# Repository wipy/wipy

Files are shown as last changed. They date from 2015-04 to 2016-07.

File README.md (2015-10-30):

The WiPy project
========================
<p align="center">
  The WiPy Logo
</p>

This is the WiPy project which aims to offer a powerful, simple,
yet flexible IoT hardware and software solution. This is achieved by
combining MicroPython (https://github.com/micropython/micropython),
a lean and mean implementation of Python 3 targeted to microcontrollers,
with the CC3200 from Texas Instruments, a state of the art SoC that
combines a Cortex-M4 MCU with an ultra low power WiFi network processor.

Components in this repository:
- docs/ -- API documentation.
- hardware/ -- Schematics, and PCB files of the WiPy.
- micropython/ -- Contains the MicroPython sources (as a git submodul) used to built the latest WiPy SW release.
- misc/ -- Miscellaneous stuff like the WiPy logo.

The micropython folder is a git submodule pointing to the micropython repository, check it out with:

    $ git submodule update --init

"make" is used to build the software, or "gmake" on BSD-based systems.
You will also need bash and Python (at least 2.7 or 3.3).

To build:

    $ cd cc3200
    $ make BTARGET=application BTYPE=release BOARD=WIPY

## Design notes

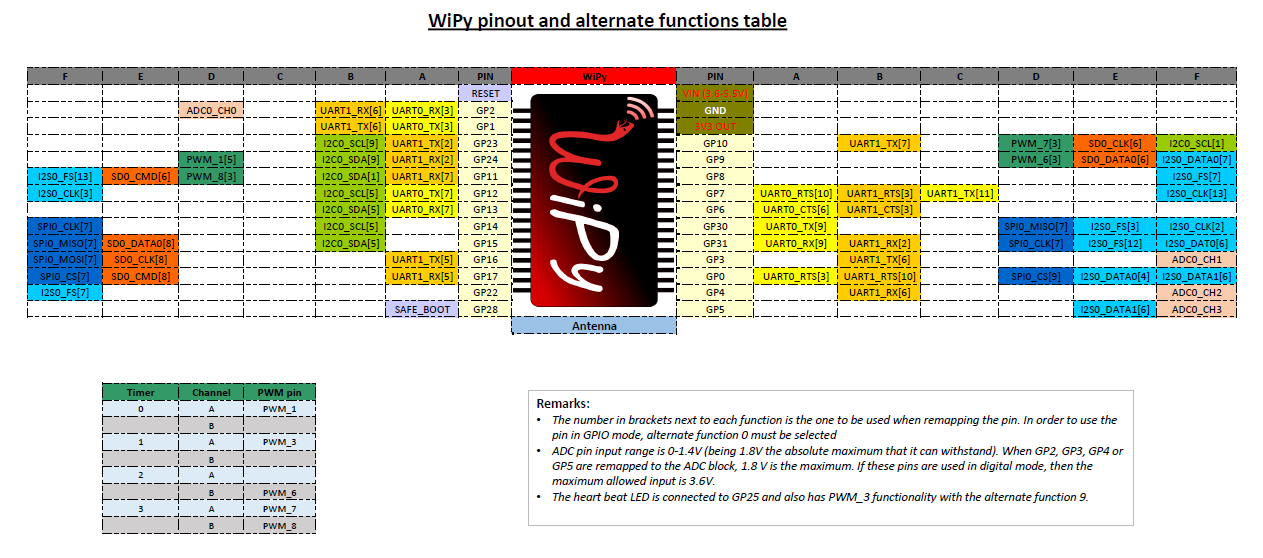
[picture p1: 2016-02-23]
docs/PinOUT.png

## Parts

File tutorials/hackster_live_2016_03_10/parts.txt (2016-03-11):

What we need:

- 1x WiPy
- 1x Expanion board
- 1x DS18B20 temperature sensor
- 1x 4k7 ohm resistor
- 1x BH1750FVI ambient light sensor
- 1x Small breadboard
- Bread board compatible cables.
- A tablet or smartphone with the Blynk App installed.
- Internet acces via WiFi for the WiPy.

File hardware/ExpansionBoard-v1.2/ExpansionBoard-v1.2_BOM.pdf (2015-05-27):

Description | RefDes | Manufacturer | Manufacturer Part No. | Quantity
Resistor_0402_63mW_5%, 27R | R5, R6 | | | 2
Resistor_0402_63mW_1%, 392R | R15 | | | 1
Resistor_0402_63mW_1%, 1K2 | R1, R3, R4, R8, R10, R13 | | | 6
Resistor_0402_63mW_1%, 2k | R11 | | | 1
Resistor_0402_63mW_5%, 10k | R12 | | | 1
Resistor_0402_63mW_1%, 56k | R16 | | | 1
Resistor_0402_63mW_5%, 100k | R2, R7, R9 | | | 3
Resistor_0402_63mW, 115k | R14 | | | 1
Ceramic_0402_NP0, 47pF/50V | C7, C8 | | | 2
Ceramic_0402_X5R, 0.1µF/10V | C2, C4, C5, C6, C9, C12, C13, 14 | | | 8
Ceramic_0603_X5R, 1µF/10V | C11 | | | 1
Ceramic_0805_X5R, 10µF/10V | C3, C10 | | | 2
FerriteBead_0805, BLM21PG600SN1D | L1 | MURATA | BLM21PG600SN1D | 1
LED_0603, LED_GREEN | D1, D2 | KINGBRIGHT | KPT-1608SGC | 2
LED_0603, LED_RED | D3 | KINGBRIGHT | KPT-1608EC | 1
P_Channel, FDC6333C | T2 | FAIRCHILD SEMICONDUCTOR | FDC6333C | 1
P_Channel, FDMA291P | T1 | FAIRCHILD SEMICONDUCTOR | FDMA291P | 1
USB_BRIDGE, FT234XD | U1 | FTDI | FT234XD-R | 1
CHARGERS, bq24040 | U2 | TEXAS INSTRUMENTS | BQ24040DSQR | 1
MUX, TPS2115A | U3 | TEXAS INSTRUMENTS | TPS2115ADRBR | 1
Connector_JST, JST | J16 | JST | S2B-XH-A (LF)(SN) | 1
Connector_SD, SD-105027-001 | J3 | MOLEX | 105027-0001 | 1
Connector_SSQ, SSQ-114-03-G-S | J1, J2, J4, J5 | SAMTEC | SSQ-114-02-G-S-RA | 4
Connector_USB, MICROUSB | J15 | FCI | 10118192-0001LF | 1
Jumpers, JUMPER 2 2.54mm | JP3 | | | 7
SWITCHES, TS-1185 | S1 | Hooya | TS-1185 | 1
Total | 53

Bill of materials - WiPy Expansion board v1.2

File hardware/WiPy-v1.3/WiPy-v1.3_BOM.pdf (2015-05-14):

Description | RefDes | Manufacturer | Manufacturer Part No. | Quantity
Resistor_0402_100mW_5%, 270R | R1 | | | 1
Resistor_0402_63mW_5%, 2K7 | R11 | | | 1
Resistor_0402_63mW_5%, 10k | R3 | | | 1
Resistor_0402_63mW_1%, 30K1 | R16 | | | 1
Resistor_0402_63mW_1%, 51K | R15 | | | 1
Resistor_0402_63mW_5%, 100k | R2, R4, R6, R9, R10, R12, R13, R14 | | | 8
Ceramic_0402_NP0, 6.2pF/50V | C10, C11 | | | 2
Ceramic_0402_NP0, 10pF/50V | C2, C3, C4, C5, C6 | | | 5
Ceramic_0402_NP0, 18pF/50V | C31 | | | 1
Ceramic_0402_NP0, 33pF/50V | C1, C7 | | | 2
Ceramic_0402_X5R, 0.1µF/10V | C8, C9, C15, C16, C17, C21, C22, C23, C25, C26, C27, C28, C29 | | | 13
Ceramic_0402_X5R, 4.7µF/6V3 | C12, C13, C14 | | | 3
Ceramic_0603_X5R, 10µF/6.3V | C20, C24 | | | 2
Ceramic_0603_X5R, 22µF/6.3V | C18, C19 | | | 2
Ceramic_0805_X5R, 10µF/10V | C30, C32 | | | 2
INDUCTORS, LQM2HPN1R0MJ0L | L2 | Murata | LQM2HPN1R0MJ0L | 1
INDUCTORS, LQM2HPN2R2MG0L | L1, L3 | Murata | LQM2HPN2R2MG0L | 2
Filters, DEA202450BT-1294C1-H | FL1 | TDK-Epcos | DEA202450BT-1294C1-H | 1
LED_0603, LED_BLUE | D1 | EVERLIGHT | 19-217/BHC-ZL1M2RY/3T | 1
N_CHANNEL, BSS138PW | T1 | NXP | BSS138PW | 1
P_Channel, FDMA291P | T2 | FAIRCHILD SEMICONDUCTOR | FDMA291P | 1
Crystals, 32.768kHz, 12.5pF | X1 | ABRACON | ABS07-32.768KHZ-T | 1
CRYSTALS, 40.000MHZ, 8pF | X2 | AVX | CX2520DB40000D0FLJCC | 1
FlashMemory, W25Q16DVZPIG | U3 | Winbond | W25Q16DVZPIG | 1
LowDrop, TPS79601DRB | U4 | TEXAS INSTRUMENTS | TPS79601DRBR | 1
RF_SWITCH, SKY13350-385LF | U2 | Skyworks | SKY13350-385LF | 1
TI, CC3200R1M2 | U1 | Texas Instruments | CC3200R1M2RGC | 1
SWITCHES, TS-1185 | S1 | Hooya | TS-1185 | 1
UFL, HJBRIGHT | ANT2 | HJBRIGHT | P1163-0140R | 1
Antennas, FR05-S1-N-0-001 | ANT1 | Fractus | FR05-S1-N-0-001 | 1
Total | | | | 61

## Bill of materials - WiPy v1.3

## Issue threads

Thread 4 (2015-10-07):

Hidden messages in PinOUT.xlsx

doctorjames, 2015-10-07:
I've just noticed there appears to be some advertising hidden in white text in the background of the pin out diagram. Not speaking Dutch, I'm not entirely sure what it says!

danicampora, 2015-10-07:
Hi @doctorjames can you show me where? (screenshot maybe...) I cannot see it...

doctorjames, 2015-10-07:
Sure, see attached. (Strangely github wouldn't accept a pdf upload despite claiming it did.)

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

dpgeorge, 2015-10-07:
oops!

danicampora, 2015-10-18:
Solved in https://github.com/wipy/wipy/commit/1b79563e3fb67ecc0384bc383f4ec1930fc9d5b2

Closed 2015-10-18.

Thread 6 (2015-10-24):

User manual Super expansion board incomplete

Mast3rChief, 2015-10-24:
The user manual is incomplete.
- For example a list of abbreviation is missing.
- I have trouble finding out how to use the user button or switch.

My suggestion is, could you upload the latex file or the raw file you used to compile the PDF. One could add information to the manual for better understanding.

danicampora, 2015-10-24:
Thanks, we'll look into that.

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

mbevilacqua, 2016-05-06:
What user manual? I didn't get any user manual with the WiPy's not the expansion boards... :-?

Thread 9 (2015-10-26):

Source download of release is missing source

doctorjames, 2015-10-26:
The tar and zip files of the new release do not include the actual source contained in the **micropython** git submodule. The **README.md** states to:

    cd cc3200
    make BTARGET=application BTYPE=release BOARD=WIPY

If the sourcecode was actually there, from the location of **README.md** presumably this should be:

    cd micropython/cc3200

You also need some instructions on setting up cross-compiling. On *debian* this involves:

    sudo apt-get install gcc-arm-none-eabi

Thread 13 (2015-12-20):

Timer class is broken

deshipu, 2015-12-20:
As per http://forum.micropython.org/viewtopic.php?f=11&t=1057&p=7646 the Timer class examples from the documentation don't work and according to @danicampora the whole class needs fixing.

deshipu, 2016-02-23:
I saw the release https://github.com/wipy/wipy/releases/tag/1.2.0 and since it mentions fixing the Timer class, I tried it immediately. Unfortunately, while I didn't get an error with ``freq=50`` this time, I also couldn't get a PWM signal on any pin.

It seems that as soon as I initialize the channel corresponding to a pin into PWM mode, that pin switches to ``Pin.IN`` mode.

danicampora, 2016-02-23:
Hi @deshipu,

Please check the docs again, since the API is has changed a bit. First of all Timer IDs start at 0 now (but you already got that right), also since the PWM dutcy cycle with 1% resolution was very bad, not the resolution has been change to 0.01% using fixed point, so, if you want a duty cycle of 50.15, then you have to pass 5015 as value. Also, since PWM pins are fixed, when creating a PWM channel, the corresponding Pin is automatically configured in PWM mode. Try this:

```python
from machine import Timer

tim = Timer(0, mode=Timer.PWM)
ch = tim.channel(Timer.A, freq=50, duty_cycle=5000)
```
And that will create a 50Hz duty cycle PWM signal on GP24 with a 50% duty cycle.

Docs link: https://micropython.org/resources/docs/en/latest/wipy/library/machine.Timer.html

Cheers,
Daniel

P.S.: Sorry for the super long delay on this fix...

bulislaw, 2016-02-23:
Ha! It works now, thanks :) Just one one day after I got my servo!

danicampora, 2016-02-23:
Haha awesome! Post some videos if you can :-)

Cheers,
Daniel

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

Closed 2016-02-23.

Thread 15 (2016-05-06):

Missing manual for the Expansion Board v2.1 (2016)

mbevilacqua, 2016-05-06:
Expansion board feels nice but a manual would be much better.

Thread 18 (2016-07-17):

Later releases are available directly from micropython.org.

gpshead, 2016-07-17:
Is this repo still useful? The latest releases of MicroPython for the WiPy seem to be available directly from https://micropython.org/download/ rather than the rather "old" 1.6 release currently available here.

niallp, 2017-01-27:
I tried building from the micropython head (v1.8.7) and while I got mcuimg.bin without errors and it nominally runs, the ftp server hangs on login (so updating firmware needs a safeboot etc.)

wipy release numbering seems to have been reset, most recent is 1.3.0, using v1.8.2 of micropython

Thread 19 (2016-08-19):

WiPy is behind MicroPython mainline in updates

pfalcon, 2016-08-19:
From https://github.com/wipy/wipy/releases/tag/v1.3.0:

> Update to release v1.8.2.

Why update to a previous release, if 1.8.3 is out for couple of weeks? There were already reports of people trying some features from micropython-lib (which is in general require the latest release of MicroPython), and having issues.

niallp, 2017-01-27:
the ftp server appears broken in a build of the latest micropython (v1.8.7), it appears the wipy 1.0 is yet another orphan (getting quite the collection ... :-/

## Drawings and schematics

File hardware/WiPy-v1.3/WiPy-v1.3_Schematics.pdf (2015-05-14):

## VCC_3V3

## Vsys

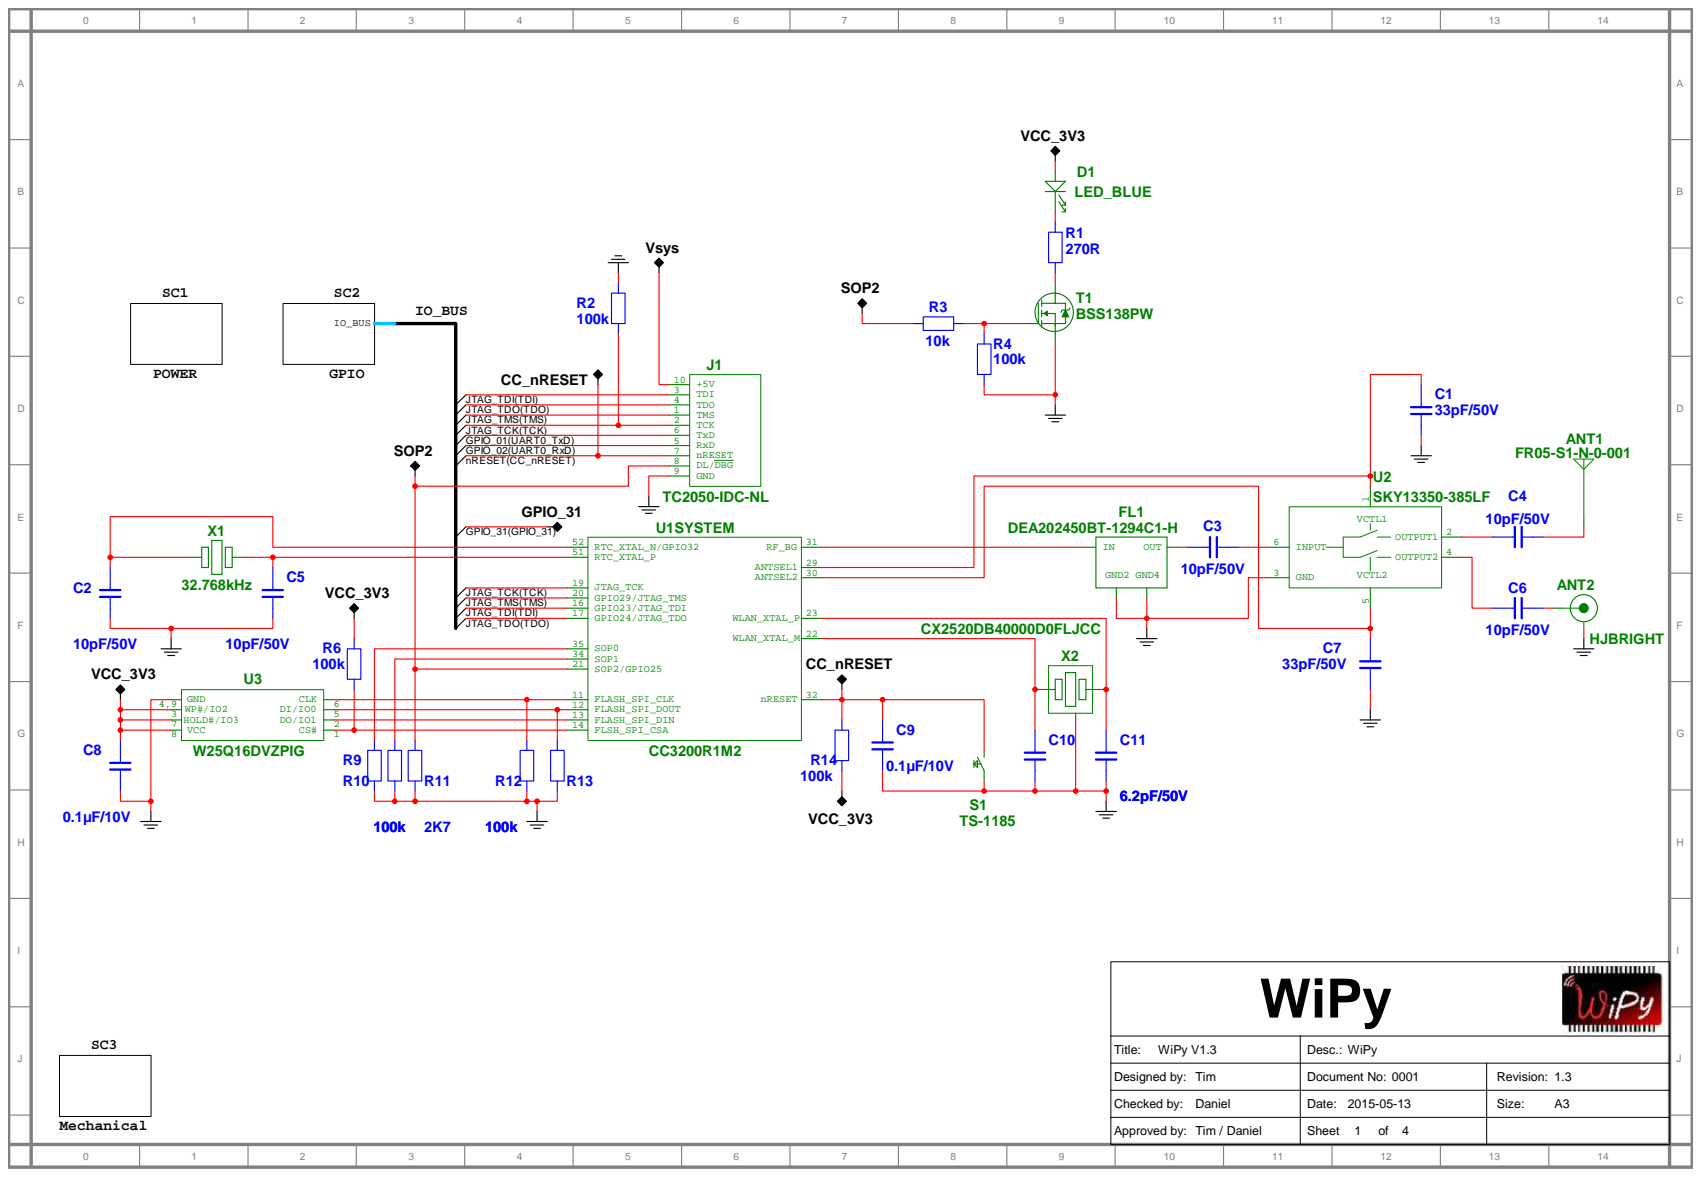
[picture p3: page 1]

## IO_BUS

## U1IO

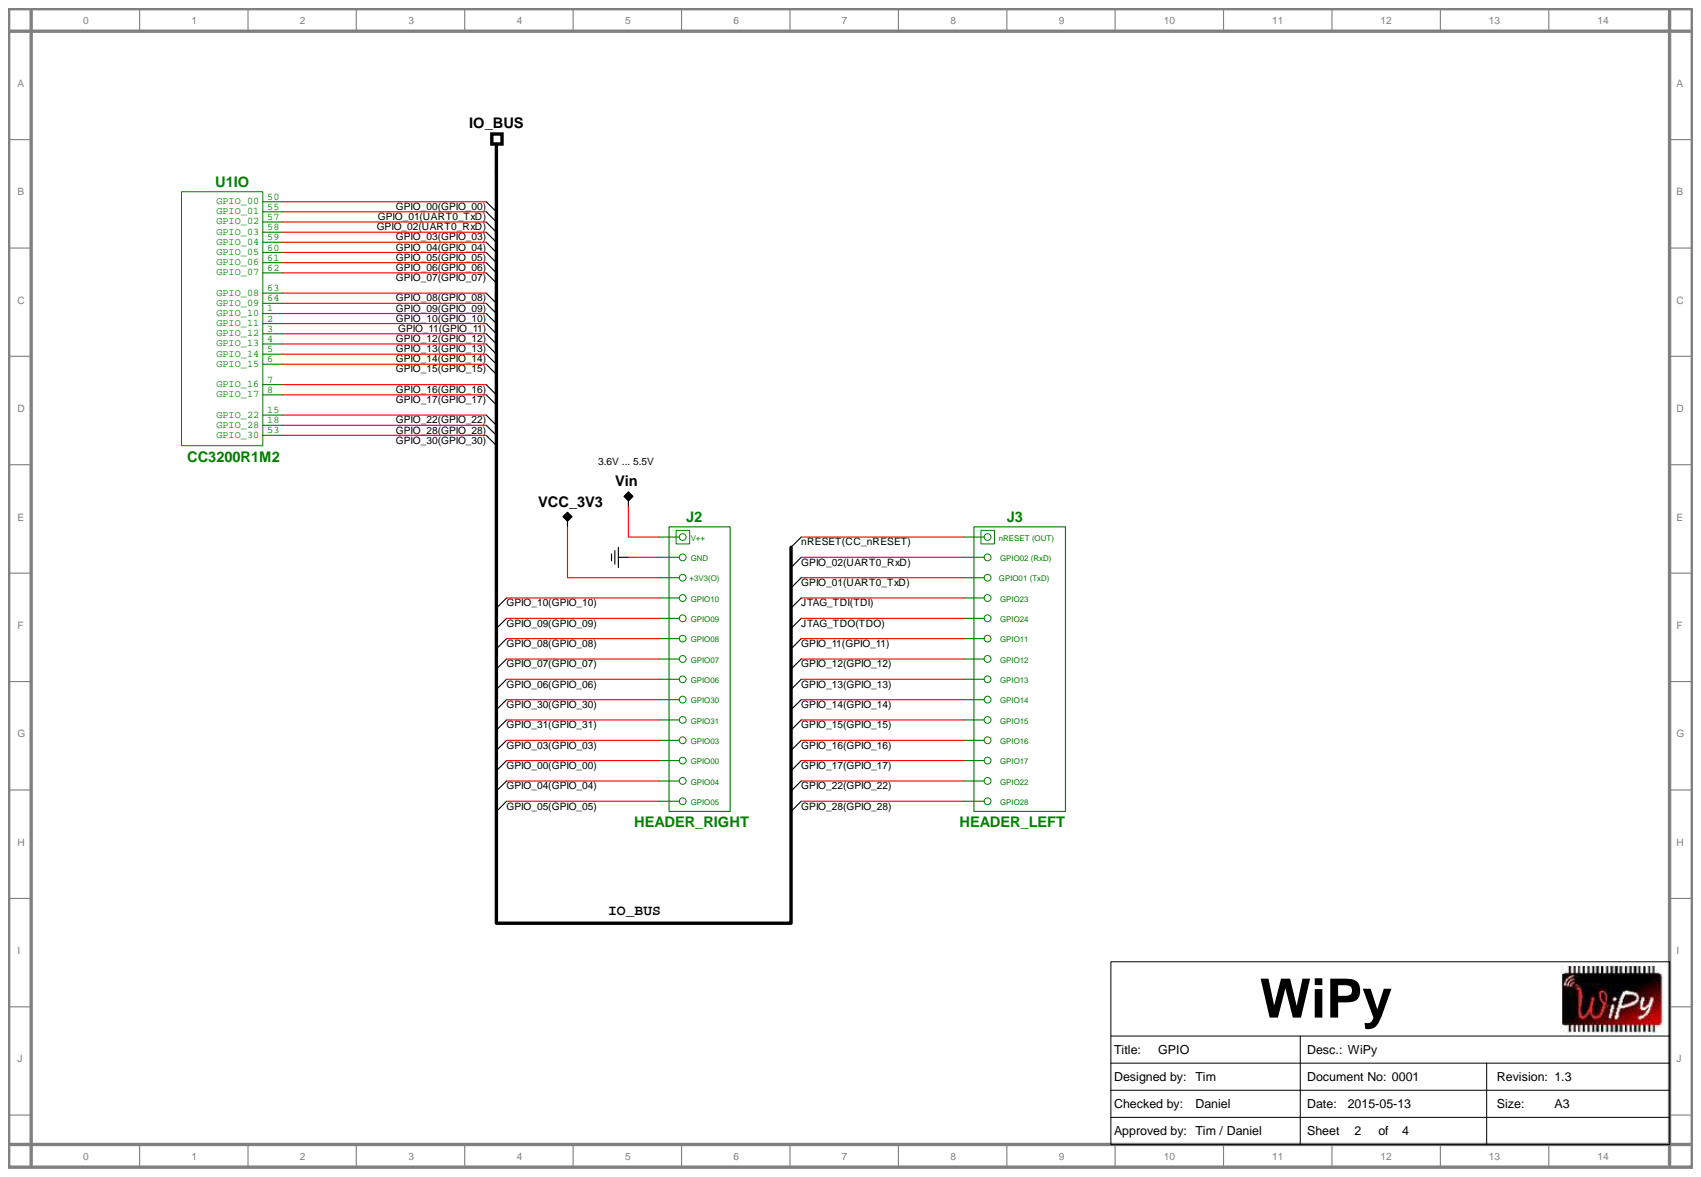
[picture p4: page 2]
HEADER_RIGHT; GND; GPIO10; GPIO09; GPIO08; GPIO07; GPIO06; GPIO30; GPIO31; GPIO03; GPIO00; GPIO04; GPIO05; GPIO_00( GPIO_00) GPIO_01( UART0_TxD) GPIO_02( UART0_RxD) GPIO_03( GPIO_03) GPIO_04( GPIO_04) GPIO_05( GPIO_05) GPIO_06( GPIO_06) GPIO_07( GPIO_07); GPIO_08( GPIO_08) GPIO_09( GPIO_09) GPIO_10( GPIO_10) GPIO_11( GPIO_11) GPIO_12( GPIO_12) GPIO_13( GPIO_13) GPIO_14( GPIO_14) GPIO_15( GPIO_15); GPIO_16( GPIO_16) GPIO_17( GPIO_17); GPIO_22( GPIO_22) GPIO_28( GPIO_28) GPIO_30( GPIO_30)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

C12

## 4.7µF/6V3

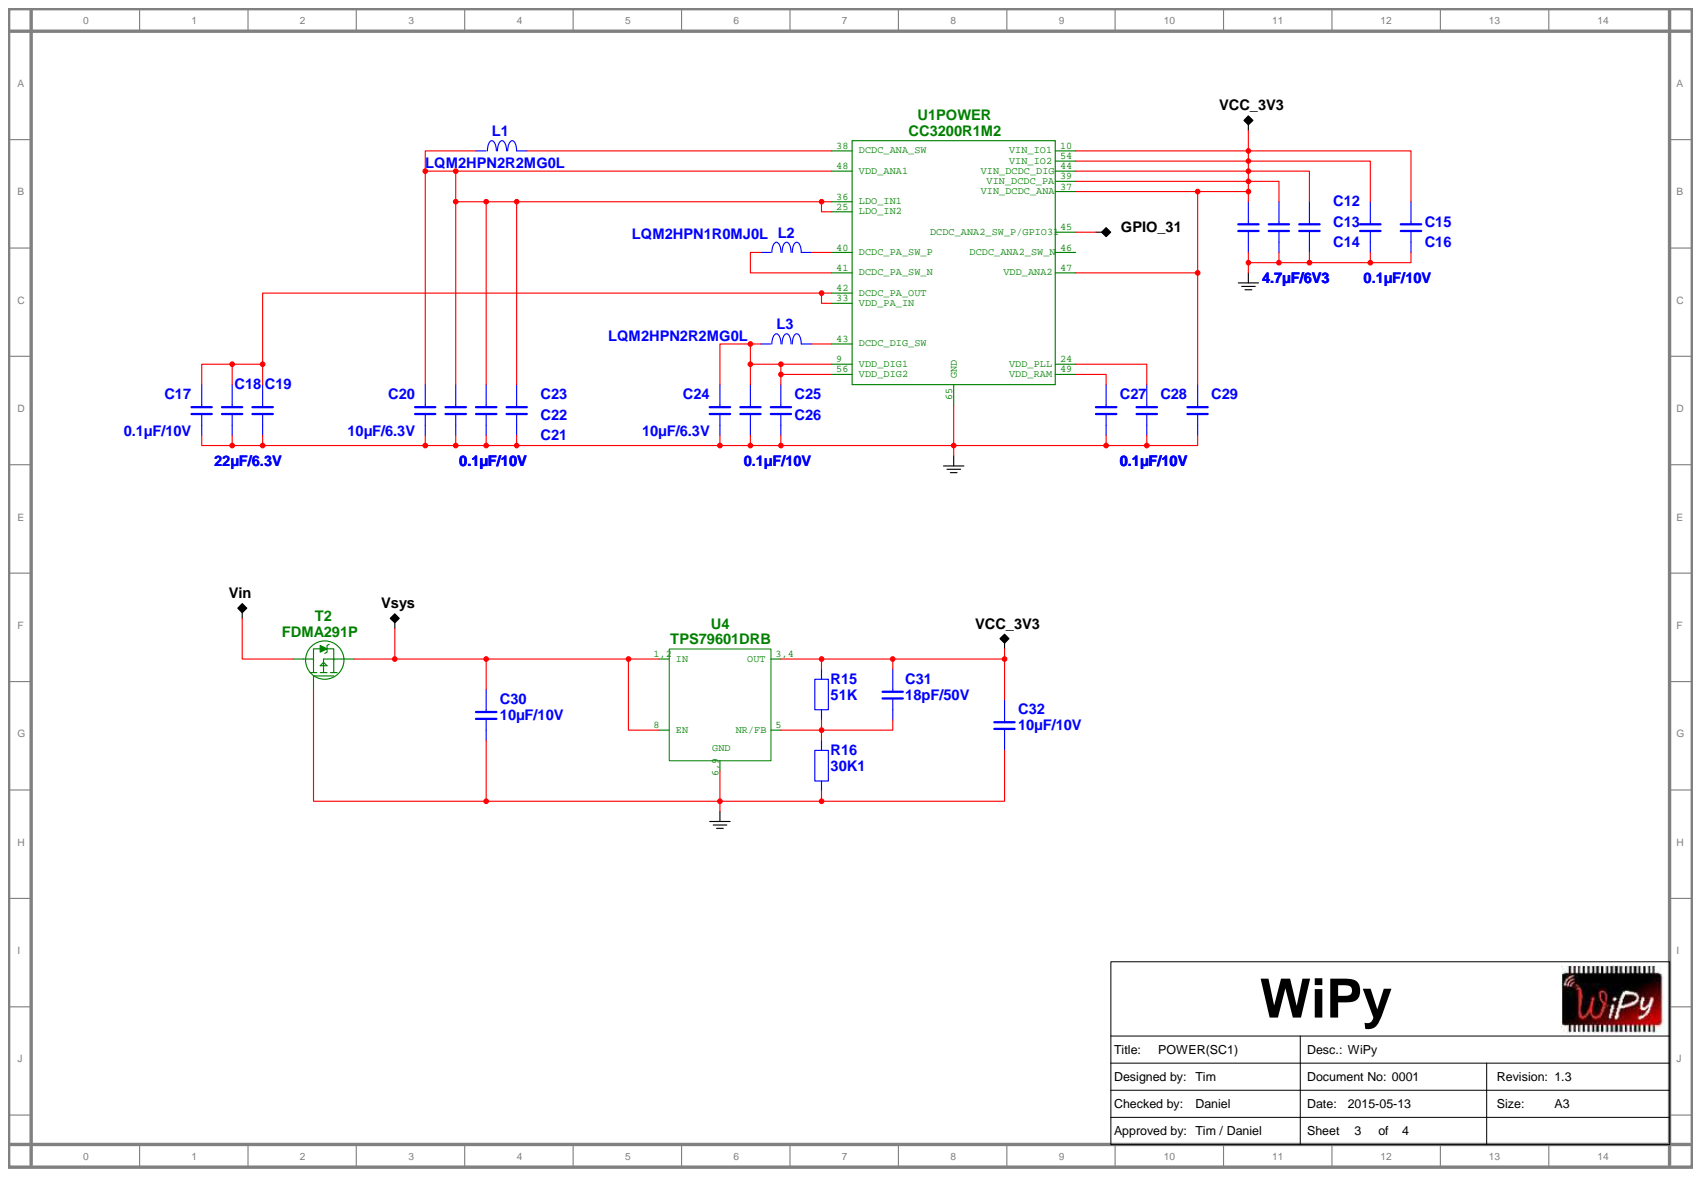
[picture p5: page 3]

H1

## mountpoint_corner_1.5

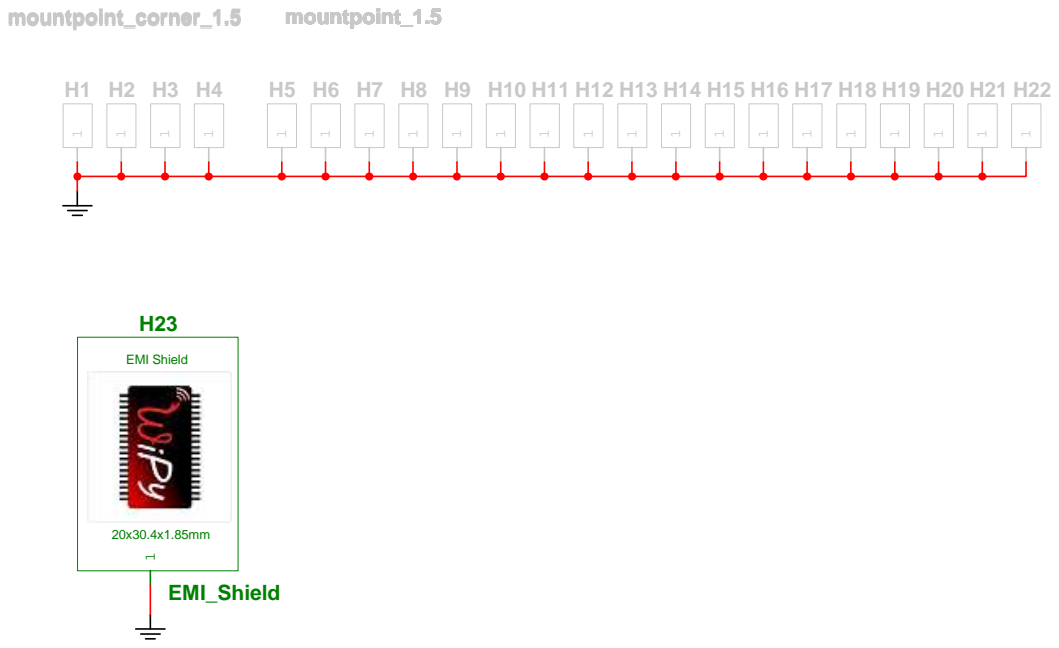
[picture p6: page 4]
mountpoint_1.5; Title:; Designed by:; Checked by:; Document No:; Date:; Revision:; Size:; Mechanical; WiPy; Tim; Daniel; Desc.:; EMI_Shield; EMI Shield

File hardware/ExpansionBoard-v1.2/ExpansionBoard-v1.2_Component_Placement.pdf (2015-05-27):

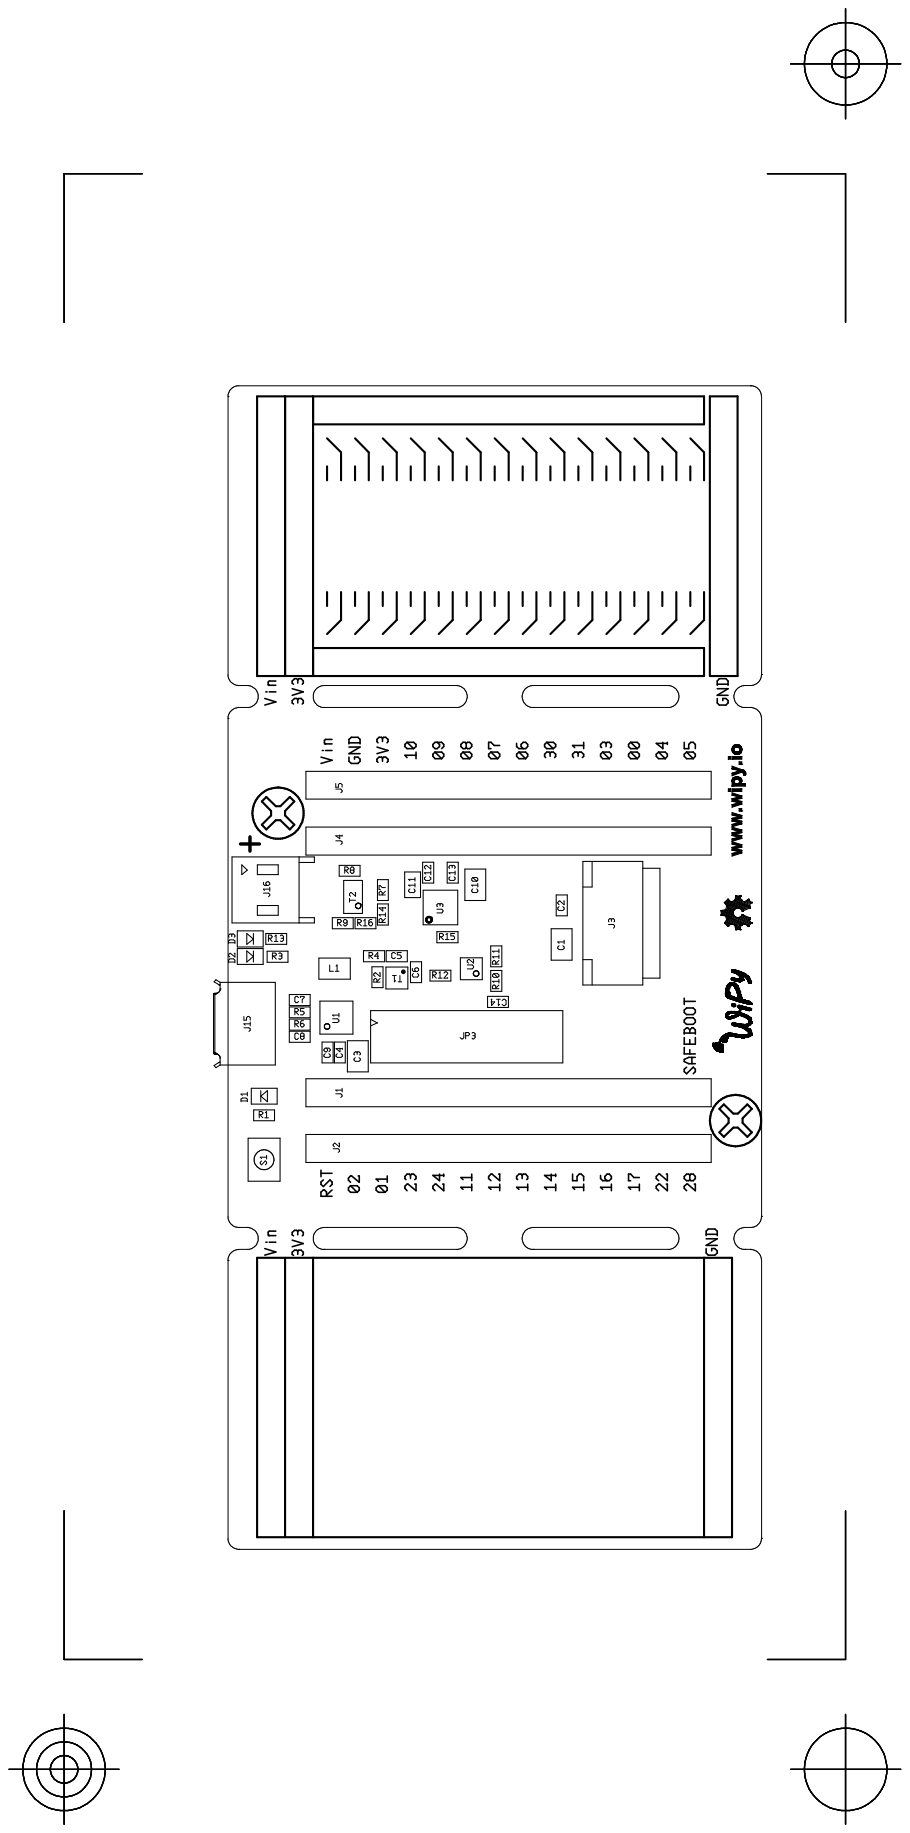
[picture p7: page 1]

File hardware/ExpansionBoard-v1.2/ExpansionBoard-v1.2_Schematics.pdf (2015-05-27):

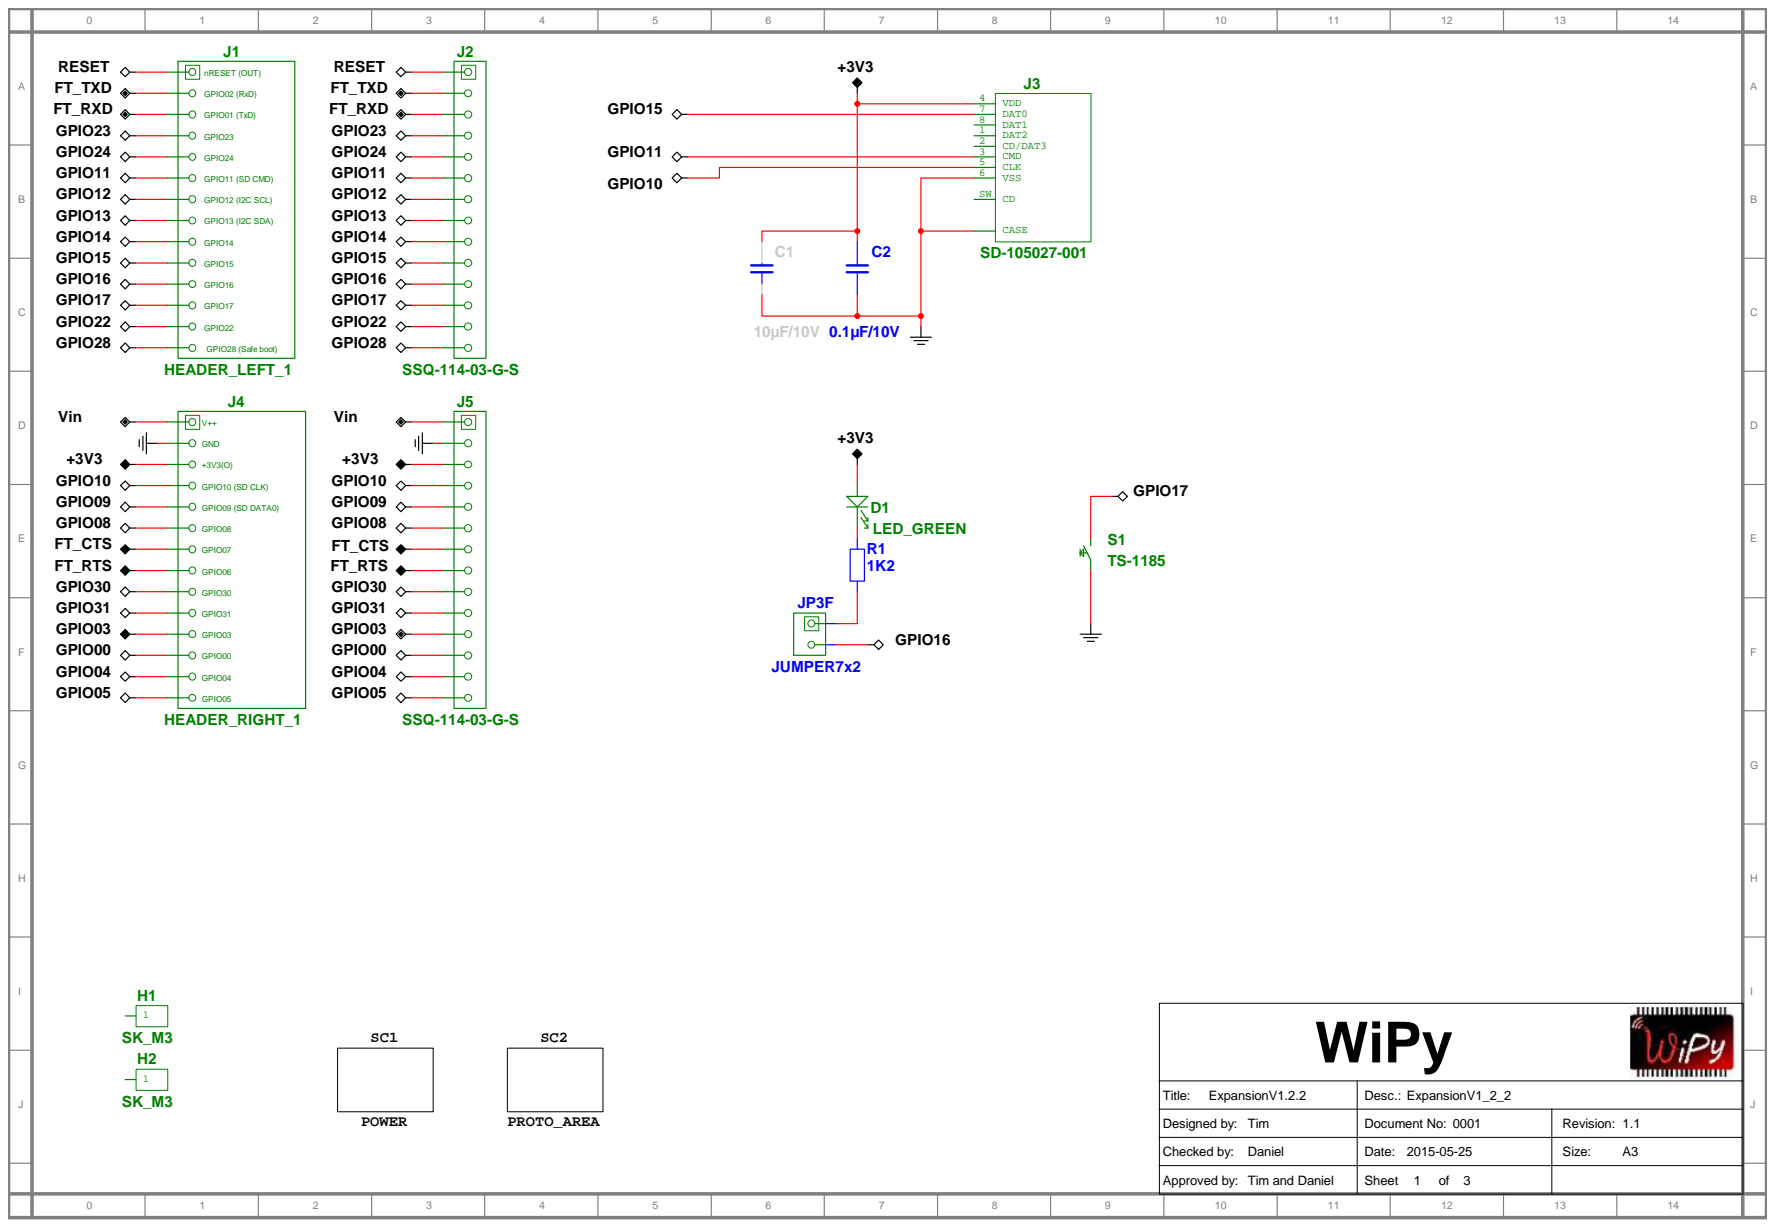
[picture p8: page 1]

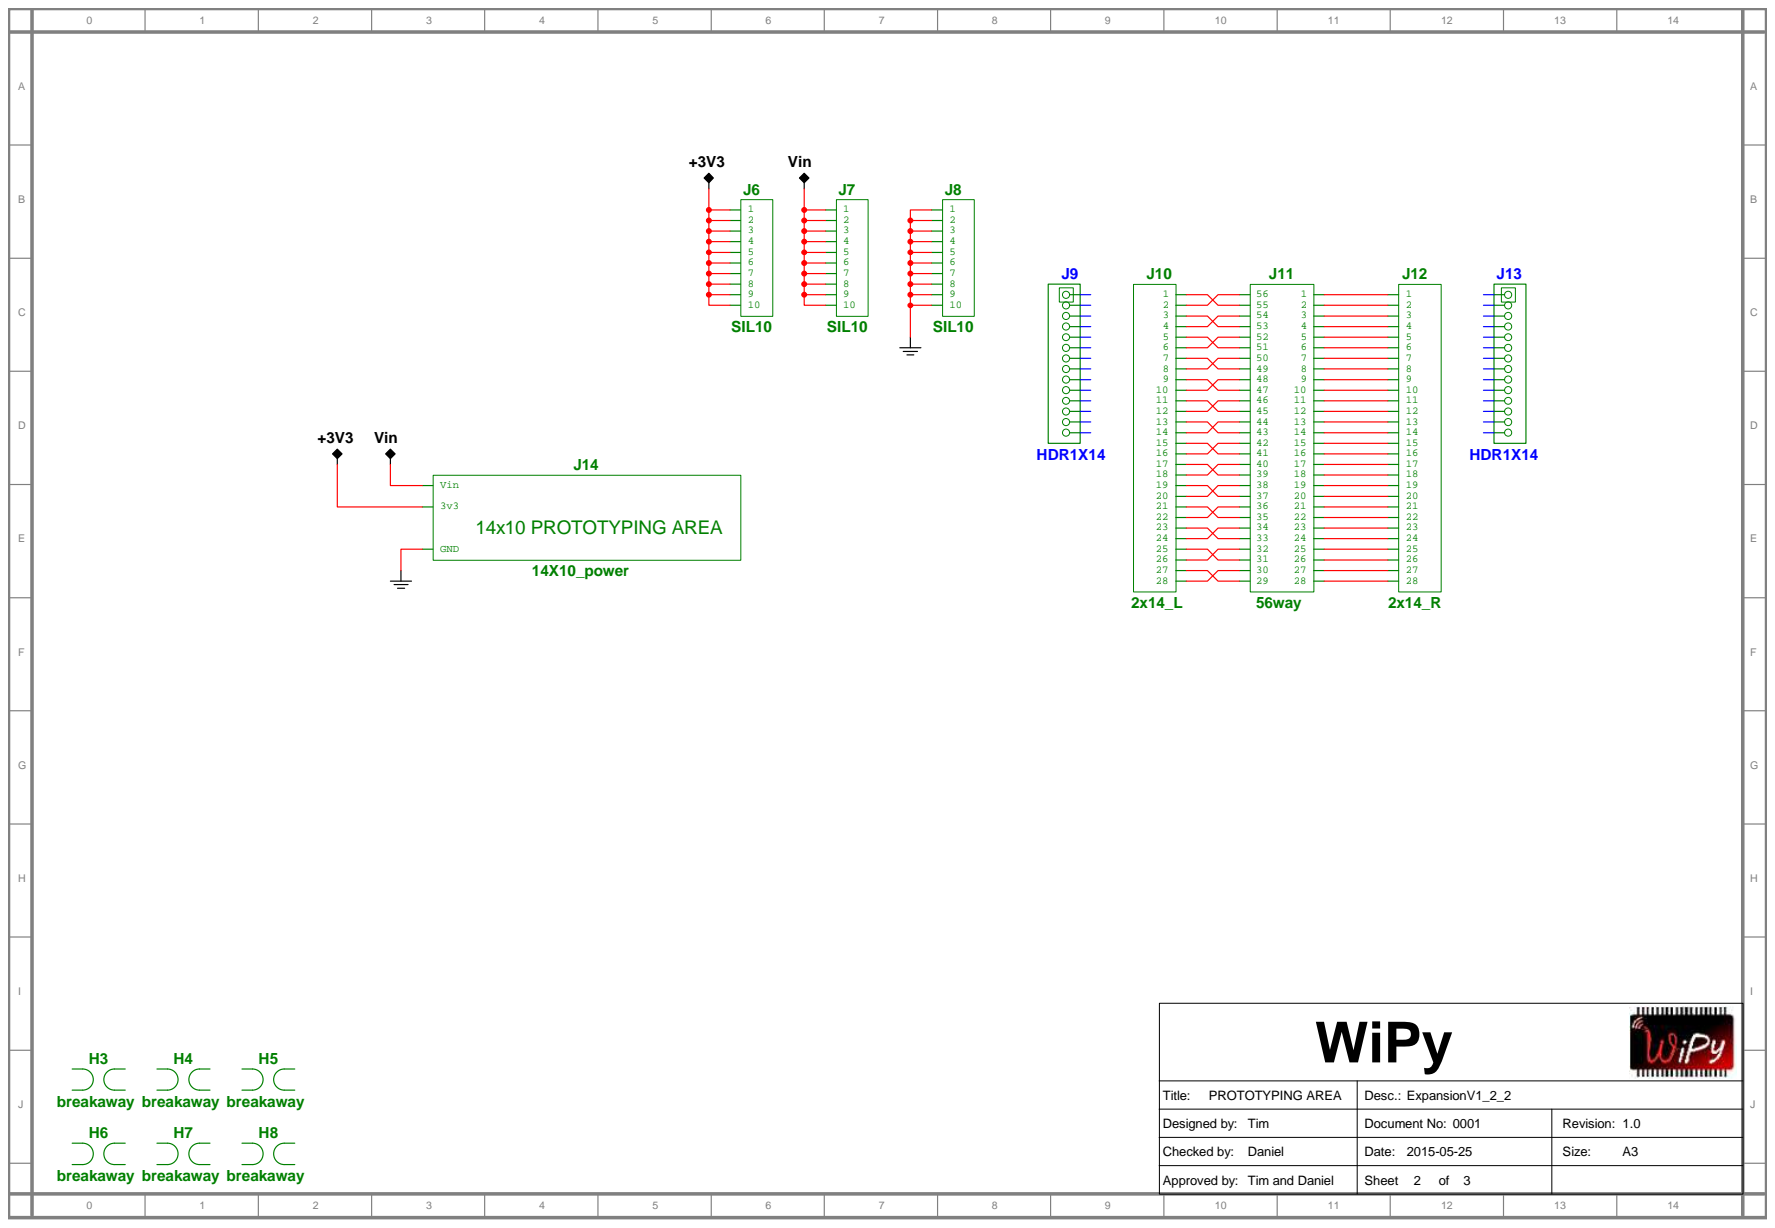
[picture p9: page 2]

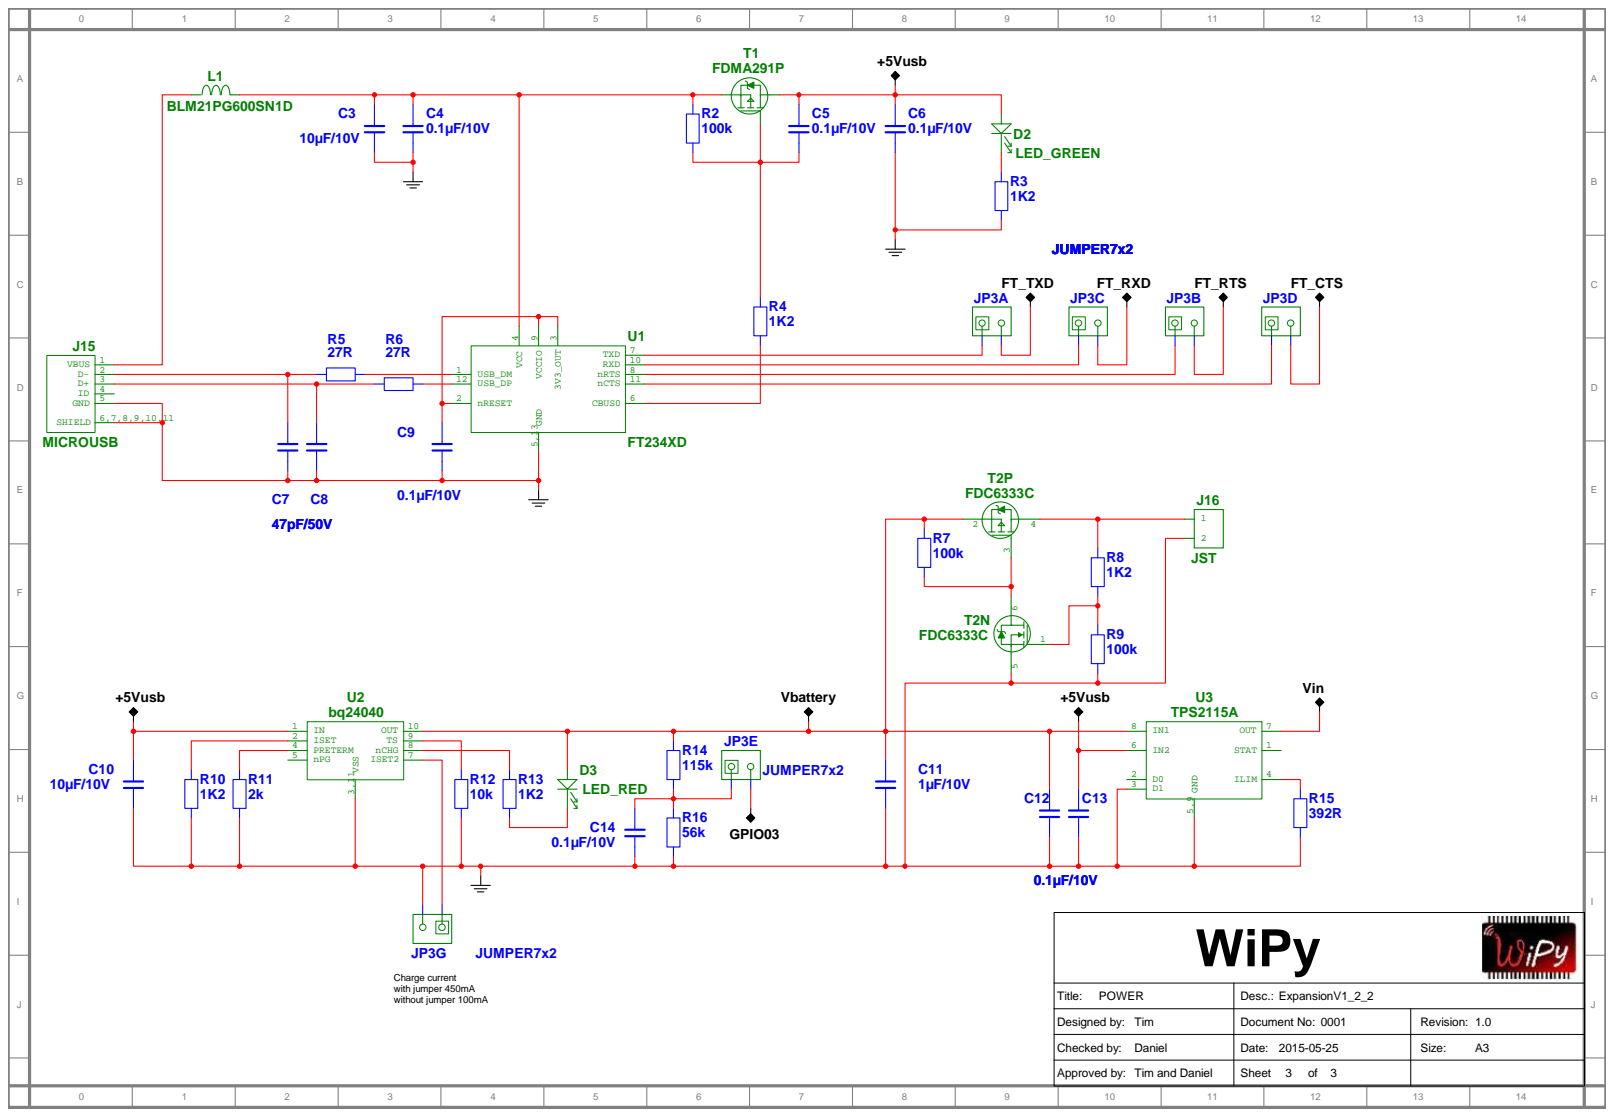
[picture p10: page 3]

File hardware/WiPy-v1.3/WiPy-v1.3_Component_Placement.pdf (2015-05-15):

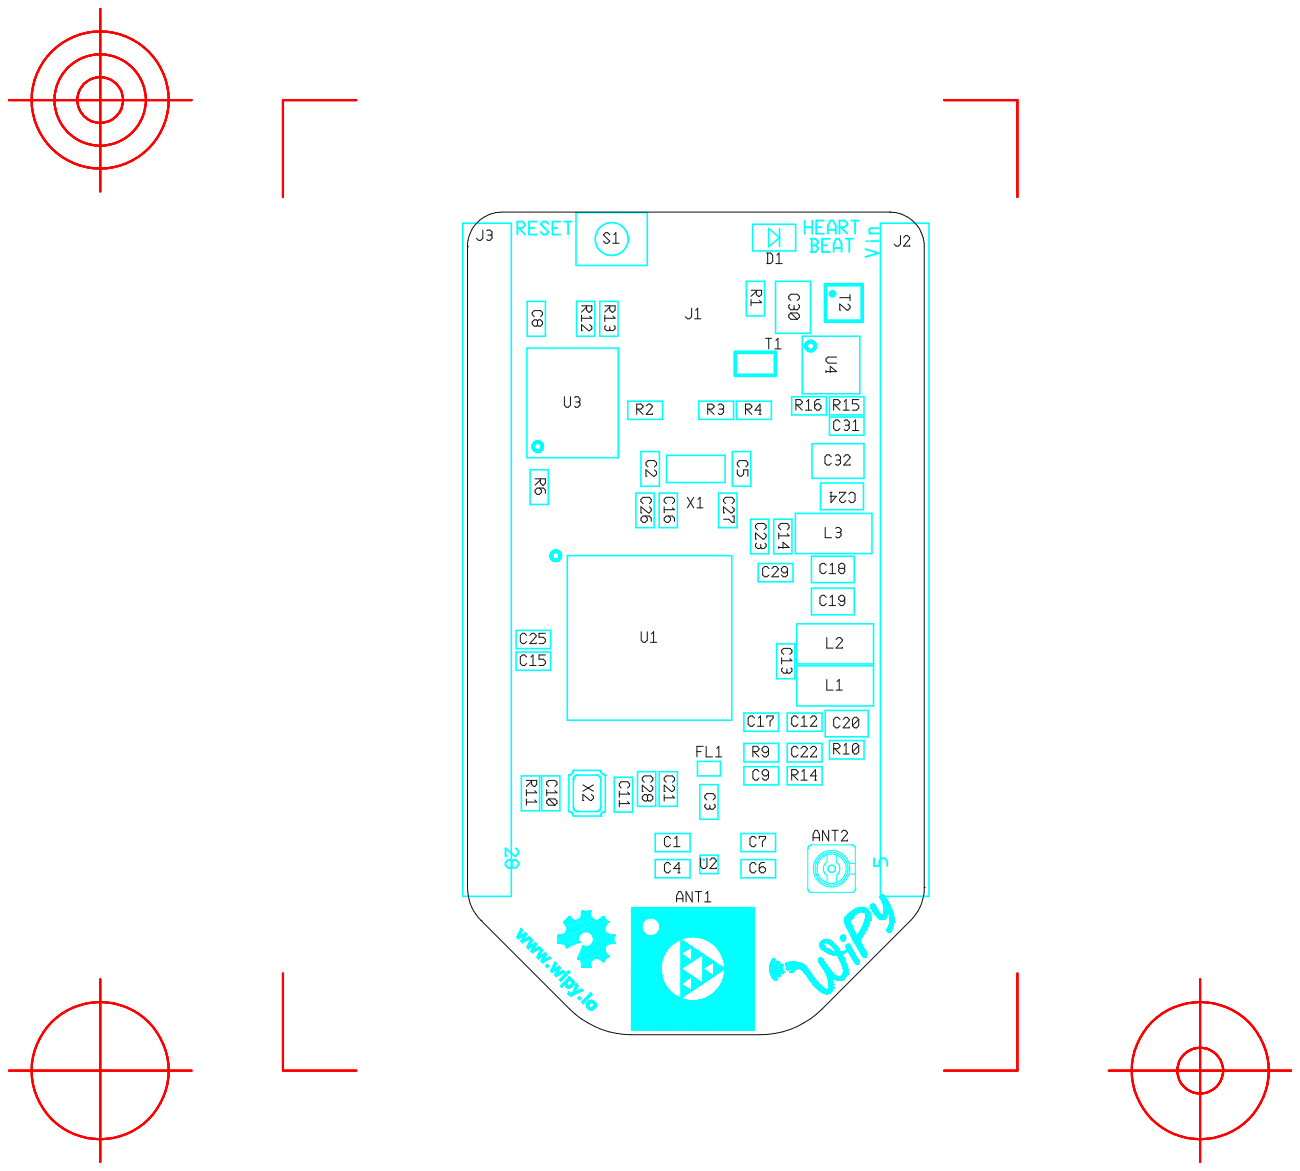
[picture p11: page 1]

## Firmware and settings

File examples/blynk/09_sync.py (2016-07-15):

"""
Blynk is a platform with iOS and Android apps to control
Arduino, Raspberry Pi and the likes over the Internet.
You can easily build graphic interfaces for all your
projects by simply dragging and dropping widgets.

  Downloads, docs, tutorials: http://www.blynk.cc
  Blynk community:            http://community.blynk.cc
  Social networks:            http://www.fb.com/blynkapp
                              http://twitter.com/blynk_app

Don't forget to change WIFI_SSID, WIFI_AUTH and BLYNK_AUTH ;)
"""

import BlynkLib
from network import WLAN

WIFI_SSID  = 'YOUR_WIFI'
WIFI_AUTH  = (WLAN.WPA2, 'YOUR_PASS')
BLYNK_AUTH = 'YOUR_AUTH_TOKEN'

# connect to WiFi
wifi = WLAN(mode=WLAN.STA)
wifi.connect(WIFI_SSID, auth=WIFI_AUTH)
while not wifi.isconnected():
    pass

print('IP address:', wifi.ifconfig()[0])

# initialize Blynk with security enabled
blynk = BlynkLib.Blynk(BLYNK_AUTH)

def blynk_connected():
    # You can also use blynk.sync_virtual(pin)
    # to sync a specific virtual pin
    print("Updating all values from the server...")
    blynk.sync_all()

blynk.on_connect(blynk_connected)

# start Blynk (this call should never return)
blynk.run()

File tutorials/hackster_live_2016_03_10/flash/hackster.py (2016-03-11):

#!/usr/bin/env python3

"""
This example shows how to create a dashboard to monitor temperature
and ambient light with a gauge widget. It also duplicates the
MicroPython REPL on a terminal widget (allowing on the fly hacking :-))

In your Blynk App project:
  Add a gauge widget, bind it to Virtual Pin V0.
  Add a second gauge widget, bind it to Virtual Pin V1.
  Add a Terminal widget, bind it to Virtual Pin V2.
  Run the App (green triangle in the upper right corner).

Don't forget to change WIFI_SSID, WIFI_AUTH and BLYNK_AUTH ;)
"""

import config
import onewire
import BlynkLib
import machine
import os
from machine import Pin
from machine import RTC
from machine import I2C
from network import WLAN
from bh1750fvi import BH1750FVI

WIFI_SSID  = config.ssid
WIFI_AUTH  = config.auth
BLYNK_AUTH = config.token

MAIN_TASK_PERIOD = const(50)


def connect_to_wlan(wlan):
    # try connecting to wifi until succeeding
    while True:
        try:
            wlan.connect(WIFI_SSID, auth=WIFI_AUTH, timeout=7500)
            while not wlan.isconnected():
                machine.idle()
            return
        except OSError:
            pass


class MainTask:
    BH1750FVI_ADDR = const(35)

    def __init__(self, blynk, ow_pin, i2c_pins, period):
        self.blynk = blynk
        self.ds18b20 = onewire.DS18X20(onewire.OneWire(Pin(ow_pin)))
        i2c = I2C(baudrate=100000, pins=i2c_pins)
        self.bh1750fvi = BH1750FVI(i2c, BH1750FVI_ADDR, period)
        self.ds_state = 'CONV'
        self.lux = 0
        self.enabled = True

    def run(self):
        if self.enabled:
            if self.ds_state == 'CONV':
                self.ds18b20.start_convertion(self.ds18b20.roms[0])
                self.ds_state = 'READ'
            elif self.ds_state == 'READ':
                tmp = self.ds18b20.read_temp_async(self.ds18b20.roms[0])
                if tmp != None:
                    self.blynk.virtual_write(0, '{:02d}.{:02d}'.format(tmp // 100, tmp % 100))
                    self.ds_state = 'CONV'
    
            lux = self.bh1750fvi.read()
            if self.lux != lux:
                self.lux = lux
                self.blynk.virtual_write(1, self.lux)


# change to STA mode and connect to the configured network
wlan = WLAN(mode=WLAN.STA)
connect_to_wlan(wlan)

# set the current time (mandatory to validate certificates)
RTC(datetime=(2016, 3, 9, 19, 30, 0, 0, None))

blynk = BlynkLib.Blynk(BLYNK_AUTH, wdt=True, ssl=True) # initialize Blynk with SSL enabled

# create the user task, pin GP30 for the one wire sensor, GP11 and GP12 as SDA and SCL
s_task = MainTask(blynk, 'GP30', ('GP11', 'GP12'), MAIN_TASK_PERIOD)
blynk.set_user_task(s_task.run, MAIN_TASK_PERIOD)

term = blynk.repl(2) # register the terminal REPL on v2
os.dupterm(term)

blynk.run()

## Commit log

2015-04-11 wipy: Create the WiPy official repository.
    [PinOUT.xlsx]
2015-04-24 docs: Clarify the remark about the ADC pins maximum voltage.
    [PinOUT.xlsx]
2015-05-03 docs: Update pinout to show the board orientation.
    [PinOUT.xlsx]
2015-05-14 hardware: Add schematics and BOM of the WiPy-v1.3.
2015-05-15 hardware: Add gerbers and assembly files of the WiPy-v1.3.
    [WiPy-v1.3_Board_Outline.gbr, WiPy-v1.3_Copper_Bottom.gbr, WiPy-v1.3_Copper_Inner_1.gbr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]
2015-05-18 hardware: Add ultiboard files and move the gerbers to their own folder.
    [WiPy-v1.3_Board_Outline.gbr, WiPy-v1.3_Copper_Bottom.gbr, WiPy-v1.3_Copper_Inner_1.gbr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]
2015-05-20 hardware: Add expansion board schematics, gerbers and ultiboard files.
    [ExpansionBoard-v1.2_Parts_Centroids.csv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]
2015-05-20 hardware: Add WiPy placement and drill files.
    [WiPy-v1.3_Parts_Centroids.csv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]
2015-05-27 hardware: Update expansion board files with the new design.
    This adds C14 in front of the ADC pin that measures the LiPo battery
    voltage.
    [ExpansionBoard-v1.2_Parts_Centroids.csv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]
2015-06-09 docs: Update PinOUT table with Timer CC and PWM pins.
    [PinOUT.xlsx]
2015-07-04 lib/blynk: Add Blynk library.
    This library brings out-of-the-box Blynk support to the WiPy.
    Requires a previously established internet connection and
    a valid token string. There is a pybstub module included
    which allows to run Blynk on a PC using Python 3.
    Example usage:
    import blynk
    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
2015-07-29 docs: Rename pins from GPIO to GP.
    [PinOUT.xlsx]
2015-08-06 lib/blynk: Re-name pin names grom GPIO to GP.
2015-08-10 docs: Add IDs to the remaining relevant peripherals.
    [PinOUT.xlsx]
2015-09-10 lib/blynk: Adapt Blynk library to new Pin API.
2015-10-12 docs: Add expansion board manual.
2015-10-14 lib/blynk: Simplify virtual pin API.
    Also make it consistent with the rest of the Blynk libraries.
2015-10-17 docs: Update pin out to reflect the new API.
    [PinOUT.xlsx]
2015-10-21 lib/blynk: Heart beat LED is now controlled via the wipy module.
2015-10-22 lib/blynk: Fix incorrect function name in 02_virtual_read.py.
    [02_virtual_read.py]
2015-11-05 lib: Add WS2812 driver lib.
2015-11-18 lib/ws2812: Remove brightness method.
    It's not the correct way to set the brightness of an RGB LED.
    Propper way is to convert the color to the HLS space, change the
    lightness (and therefore the brightness) and then convert back
    to RGB.
2016-02-22 lib/blynk: Update Blynk library to support the new Timer API.
2016-02-23 docs: Update PinOUT to reflect new Timer IDs.
    [PinOUT.xlsx]
2016-03-10 lib/blynk: Correct PWM timer configuration.
2016-07-31 docs: Update expansion board manual to reflect the new form factor.
2016-12-01 Bug fix for the BH1750FVI library
    i2c i2c.writeto() requires a byte[]
